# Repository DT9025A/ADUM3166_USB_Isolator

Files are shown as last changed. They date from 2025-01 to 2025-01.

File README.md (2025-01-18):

# ADUM3166 USB 隔离器

**该项目使用 Kicad 进行设计，打板请使用附件中的 Gerber 文件或使用 Kicad 工程进行导出。**

使用 IS903 主控的 USB DISK 进行测试，读写速度如下：

读写速度

采用 5V/5W 的隔离电源，具有较大带负载能力，可以满足一般需求。



Type-C in，USB-A out。



USB 接口处放置了 ESD 二极管 H5VU25U，无需要可不焊接。

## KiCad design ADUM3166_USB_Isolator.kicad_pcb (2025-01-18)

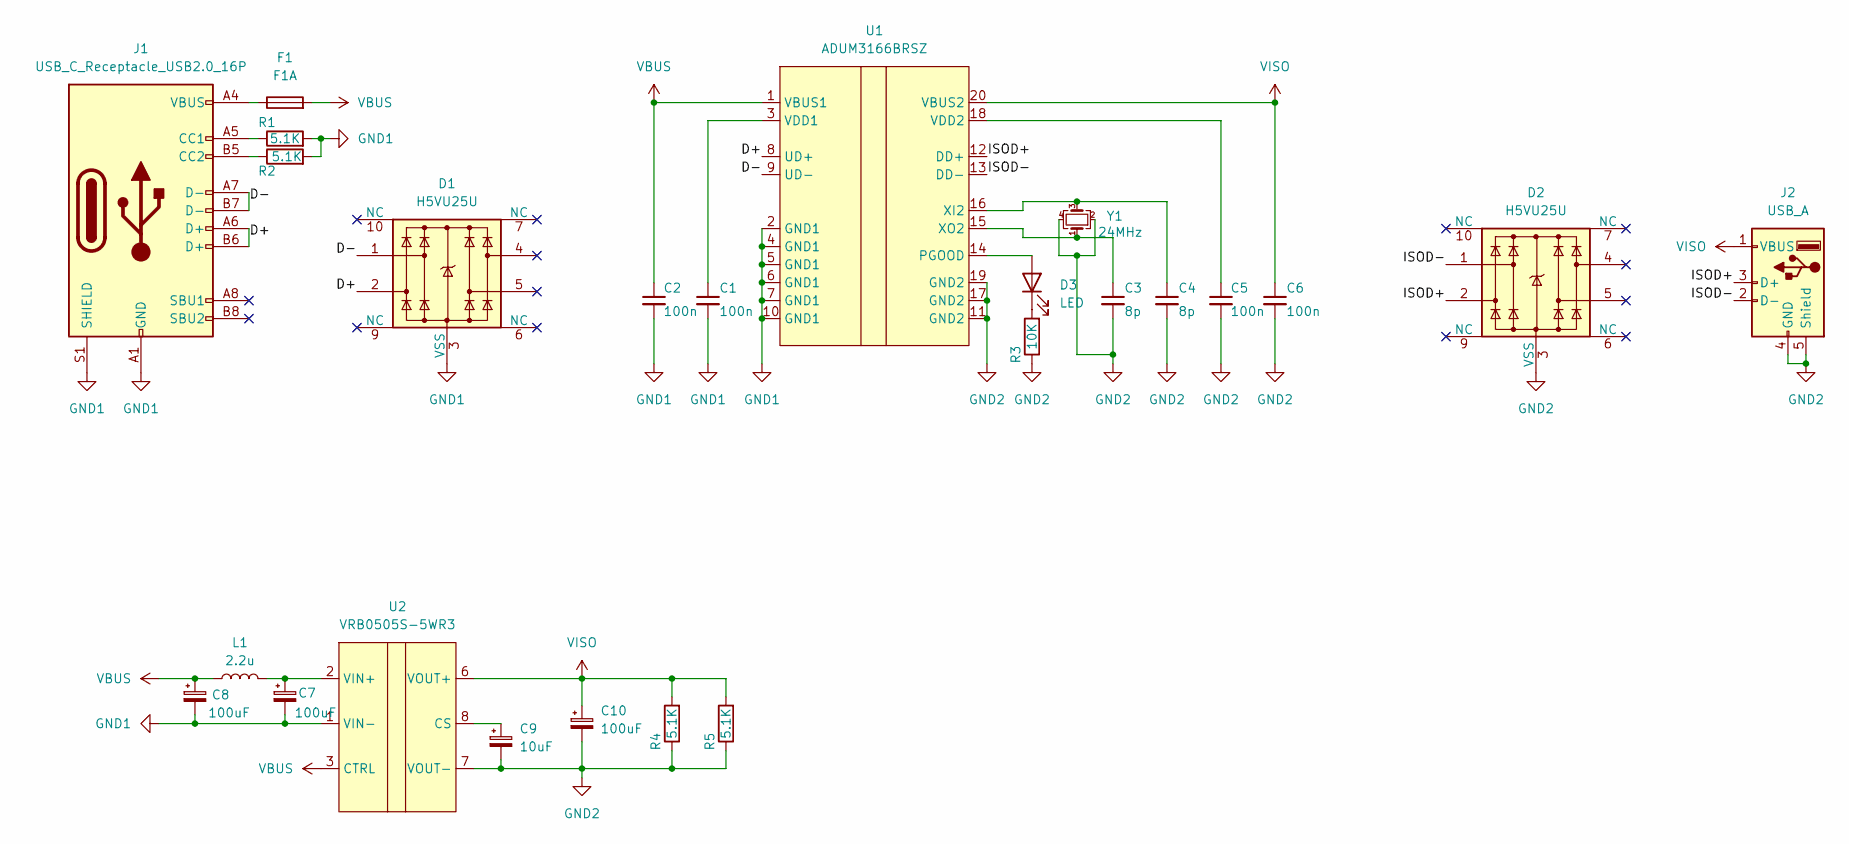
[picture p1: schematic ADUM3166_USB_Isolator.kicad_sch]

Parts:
C1, C2, C5, C6: 100n; C_0603_1608Metric_Pad1.08x0.95mm_HandSolder
C3, C4: 8p; C_0402_1005Metric_Pad0.74x0.62mm_HandSolder
C7, C8, C10: 100uF; CP_Elec_6.3x5.4
C9: 10uF; CP_Elec_4x5.4
D1, D2: H5VU25U; Diodes_UDFN-10_1.0x2.5mm_P0.5mm
D3: LED; LED_0603_1608Metric_Pad1.05x0.95mm_HandSolder
F1: F1A; Fuse_1206_3216Metric_Pad1.42x1.75mm_HandSolder
J1: USB_C_Receptacle_USB2.0_16P; USB_C_Receptacle_G-Switch_GT-USB-7010ASV
J2: USB_A; USB_A_CONNFLY_DS1095-WNR0
L1: 2.2u; L_1008_2520Metric_Pad1.43x2.20mm_HandSolder
R1, R2, R4, R5: 5.1K; R_0603_1608Metric_Pad0.98x0.95mm_HandSolder
R3: 10K; R_0603_1608Metric_Pad0.98x0.95mm_HandSolder
U1: ADUM3166BRSZ; SSOP-20_5.3x7.2mm_P0.65mm
U2: VRB0505S-5WR3; VR_S_5W
Y1: 24MHz; Crystal_SMD_2520-4Pin_2.5x2.0mm

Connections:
/D+: D1.2, J1.A6 (D+), J1.B6 (D+), U1.8 (UD+)
/D-: D1.1, J1.A7 (D-), J1.B7 (D-), U1.9 (UD-)
/ISOD+: D2.2, J2.3 (D+), U1.12 (DD+)
/ISOD-: D2.1, J2.2 (D-), U1.13 (DD-)
GND1: C1.2, C2.2, C7.2, C8.2, D1.3 (VSS), D1.8 (VSS), J1.A1 (GND), J1.A12 (GND), J1.B1 (GND), J1.B12 (GND), J1.S1 (SHIELD), R1.2, R2.2, U1.2 (GND1), U1.4 (GND1), U1.5 (GND1), U1.6 (GND1), U1.7 (GND1), U1.10 (GND1), U2.1 (VIN-)
GND2: C3.2, C4.2, C5.2, C6.2, C9.2, C10.2, D2.3 (VSS), D2.8 (VSS), J2.4 (GND), J2.5 (Shield), R3.1, R4.1, R5.1, U1.11 (GND2), U1.17 (GND2), U1.19 (GND2), U2.7 (VOUT-), Y1.2, Y1.4
unnamed: D3.2 (A), U1.14 (PGOOD)
unnamed: D3.1 (K), R3.2
unnamed: F1.1, J1.A4 (VBUS), J1.A9 (VBUS), J1.B4 (VBUS), J1.B9 (VBUS)
unnamed: J1.A5 (CC1), R1.1
unnamed: J1.B5 (CC2), R2.1
unnamed: C1.1, U1.3 (VDD1)
unnamed: C5.1, U1.18 (VDD2)
unnamed: C4.1, U1.16 (XI2), Y1.3
unnamed: C3.1, U1.15 (XO2), Y1.1
unnamed: C9.1, U2.8 (CS)
unnamed: C7.1, L1.2, U2.2 (VIN+)
VBUS: C2.1, C8.1, F1.2, L1.1, U1.1 (VBUS1), U2.3 (CTRL)
VISO: C6.1, C10.1, J2.1 (VBUS), R4.2, R5.2, U1.20 (VBUS2), U2.6 (VOUT+)

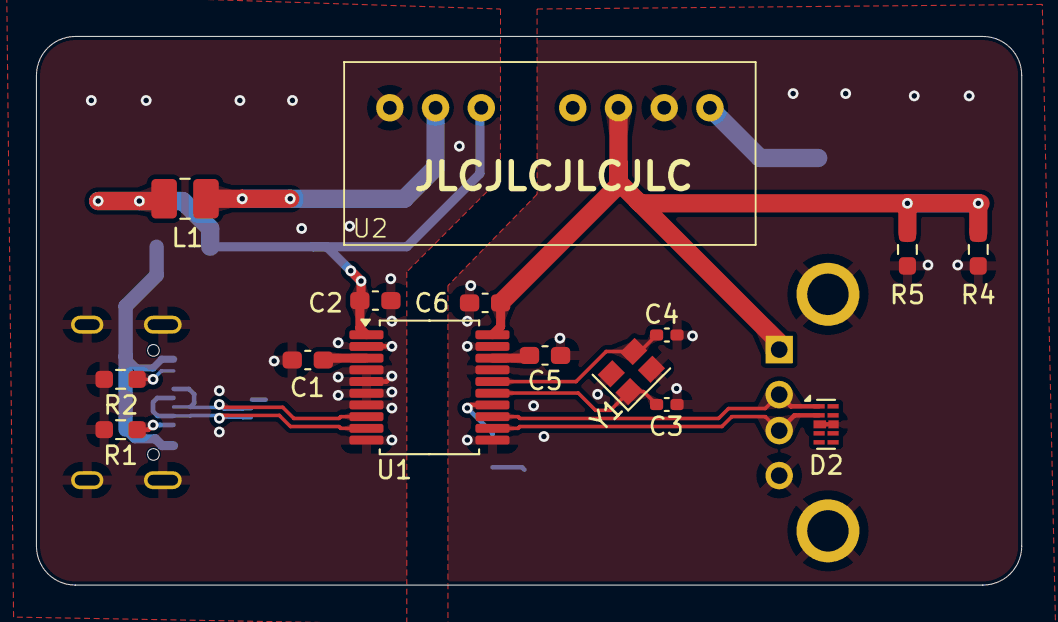
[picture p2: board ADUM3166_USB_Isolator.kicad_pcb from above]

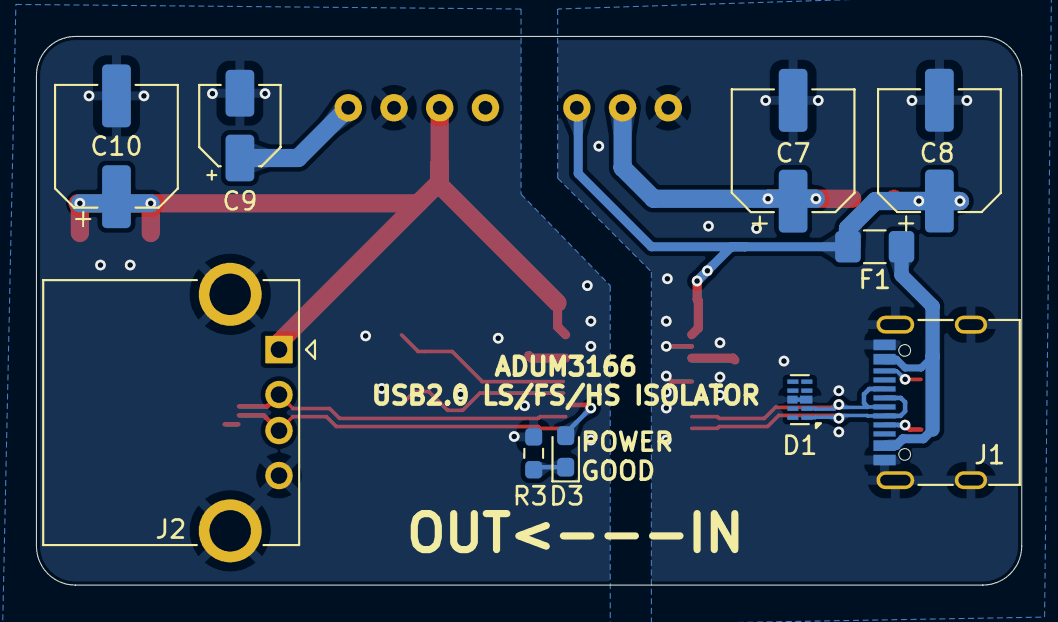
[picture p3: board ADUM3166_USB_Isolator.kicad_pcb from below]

Board: 2 copper layers, 54.7 x 30.5 mm, 25 parts (10 on the bottom side), 19 nets.
